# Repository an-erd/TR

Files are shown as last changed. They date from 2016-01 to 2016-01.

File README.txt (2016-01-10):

PURPOSE
=======
The function of TR is to have a tiny gym timer, which can give you intervals for active and rest
phases during gym or any other sport. Is has 4 buttons (1 reset button, and three functional
buttons T1..3 ), 9 leds (5 red as a progress bar, 3 orange for current phase active or rest, 
resp. (or during config), and a green heartbeat led.)
It is build on an ATMEL ATMEGA328P, but should work on any other similar MCU, too.
The power is assumed to be 3V. The code is optimized for power saving, but since the leds draw a
pretty high load, it is - by system - still consuming around 10 mA on average during training.

The program flow exist of the following steps:
- initialization (I/O pins, timer, ...)
- configuration routine
- training routine

During the phases, to control is done with the buttons, and the leds change the mode accordingly.
The specific status and control is shown in the list below.

The program itself makes heavy use of two timer, and pin change interrupts. The logic itself, in 
particular waiting for a counter to run down and to give effects and progress with the leds is
more or less completly delivered by the relevant interrupts. 

During WAITING MODE
====================
	LED PB1/green		-> slow flashing means "waiting for command"
	T1					-> (nothing yet)
	T2					-> go into config mode
	T3					-> GO! (training)

	LED PD0..7/red/ora	-> off
	LED PB1/green		-> short heartbeat

During CONFIG
=============
	T1					-> increase config parameter value, wrap-arolund 5 -> 1 or 0 resp.
	T2					-> switch to next config parameter, wrap-around is done
	T3					-> GO! (training)

	LED PD0..4/red		-> show configurated value
	LED PD5..7/orange	-> show configuration step (000/INT, 100/ACT, 110/REST, 111/cycles)
	LED PB1/green		-> fast flashing

During TRAINING
===============
	T1					-> (nothing yet)
	T2					-> Stop training and go in "waiting mode", see main loop
	T3					-> Pause training

	LED PD0..4/red		-> show progress in current phase, current step flashes, 1-5 leds
	LED PD5..7/orange	-> show LR or RL cascade to show phase ACTIVE or REST, resp.
	LED PB1/green		-> heartbeat

During PAUSE
============
	LED PD0..4/red		-> freeze current status 
	LED PD5..7/orange	-> freeze current status
	LED PB1/green		-> slow flashing

	T2					-> Stop training/pause and go in "waiting mode", see main loop
	T3					-> end pause, 

TODO and optimization
=====================
- none yet

Timer calculation/values
========================
- 8 MHz quartz, fuse CKDIV8 disabled, F_CPU=8000000UL
- timer0: 8 MHz,  8bit, 1/64  prescale -> 1 KHz (OCR0A   125 ticks / .001s=1ms)
- timer1: 8 MHz, 16bit, 1/256 prescale -> 1 Hz  (OCR1A 31250 Ticks / 1s, OCR1B 3125 Ticks / .1s)

- 8 MHz quartz, fuse CKDIV8 set, F_CPU=1000000UL
- timer0: @F_CPU/8, tick values stay unchanged
- timer1: @F_CPU/64, 1 Hz: OCR1A = 15625, 10 Hz: OCR1B =  1562

FUSE Settings are:
==================
BODLEVEL = 1V8
RSTDISBL = [ ]
DWEN = [ ]
SPIEN = [X]
WDTON = [ ]
EESAVE = [X]
BOOTSZ = 2048W_3800
BOOTRST = [ ]
CKDIV8 = [X]
CKOUT = [ ]
SUT_CKSEL = EXTXOSC_8MHZ_XX_16KCK_14CK_65MS

EXTENDED = 0xFE (valid)
HIGH = 0xD1 (valid)
LOW = 0x7F (valid)

Compiler symbols defined
========================
F_CPU=1000000UL
_PRODUCTION_TEST_ROUTINE_
_ALL_LED_ON_FOR_5_SEC_
_INCREASE_NUM_LED_ON_

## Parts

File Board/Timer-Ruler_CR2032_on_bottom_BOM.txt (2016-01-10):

Partlist

Exported from Timer-Ruler_CR2032_on_bottom.brd at 10.01.2016 20:31

EAGLE Version 7.5.0 Copyright (c) 1988-2015 CadSoft

Assembly variant: 

Part     Value                      Package          Library                                         Position (inch)       Orientation

B0       nur PAD, keine Stiftleiste 1X01             pinhead                                         (1.975 1.45)          R0
B2       nur PAD, keine Stiftleiste 1X01             pinhead                                         (1.975 1.55)          R0
JP1      nur PAD, keine Stiftleiste 2X03             pinhead                                         (1.6 1.625)           R180
LED1     Kingbright KP-2012SRC-PRV  CHIP-LED0805     led                                             (1.3 0.7)             R180
LED2     Kingbright KP-2012SRC-PRV  CHIP-LED0805     led                                             (1.4 0.7)             R180
LED3     Kingbright KP-2012SRC-PRV  CHIP-LED0805     led                                             (1.5 0.7)             R180
LED4     Kingbright KP-2012SRC-PRV  CHIP-LED0805     led                                             (1.6 0.7)             R180
LED5     Kingbright KP-2012SRC-PRV  CHIP-LED0805     led                                             (1.7 0.7)             R180
LED6     Kingbright KP-2012SECK     CHIP-LED0805     led                                             (1.8 0.7)             R180
LED7     Kingbright KP-2012SECK     CHIP-LED0805     led                                             (1.9 0.7)             R180
LED8     Kingbright KP-2012SECK     CHIP-LED0805     led                                             (2 0.7)               R180
LED9     Kingbright KP-2012CGCK     CHIP-LED0805     led                                             (2 0.875)             R0
R1       68R                        R0402            resistor                                        (1.275 0.925)         R270
R2       68R                        R0402            resistor                                        (1.325 0.925)         R270
R3       68R                        R0402            resistor                                        (1.375 0.925)         R270
R4       68R                        R0402            resistor                                        (1.425 0.925)         R270
R5       68R                        R0402            resistor                                        (1.475 0.925)         R270
R6       47R                        R0402            resistor                                        (1.725 0.9)           R270
R7       47R                        R0402            resistor                                        (1.775 0.9)           R270
R8       47R                        R0402            resistor                                        (1.825 0.9)           R270
R9       47R                        R0402            resistor                                        (1.875 0.9)           R270
R10      220R                       R0402            resistor                                        (1.26515748 1.6487313) R270
S1       431151015826               431181015816     Wurth_Elektronik_Electromechanic_Switchs_rev15b (1 1.175)             R180
S2       431151015826               431181015816     Wurth_Elektronik_Electromechanic_Switchs_rev15b (1 0.9)               R180
S3       431151015826               431181015816     Wurth_Elektronik_Electromechanic_Switchs_rev15b (1 0.625)             R180
SCL      nur PAD, keine Stiftleiste 1X01             pinhead                                         (0.9 1.4)             R90
SDA      nur PAD, keine Stiftleiste 1X01             pinhead                                         (1 1.4)               R0
U$1      FIDUCIAL                   FIDUCIAL_1MM     adafruit                                        (0.95 0.625)          R0
U$2      FIDUCIAL                   FIDUCIAL_1MM     adafruit                                        (1.975 1.675)         R90
U$3      RENATA_STMU2032            SMTU2032         Ava                                             (1.525 1.125)         MR55
U$4      C+K_AYZ0202AGRLC           C+K_AYZ0202AGRLC Ava                                             (1 1.6)               R180
U1       ATMEGA328P_TQFP            TQFP32-08        SparkFun-DigitalIC                              (1.45 1.25)           R135
Y1       8MHZ                       RESONATOR-SMD    SparkFun-FreqCtrl                               (1.625 0.975)         R45

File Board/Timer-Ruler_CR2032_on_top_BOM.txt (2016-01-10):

Partlist

Exported from Timer-Ruler_CR2032_on_top.brd at 10.01.2016 20:29

EAGLE Version 7.5.0 Copyright (c) 1988-2015 CadSoft

Assembly variant: 

Part     Value                      Package          Library                                         Position (inch)       Orientation

B0       nur PAD, keine Stiftleiste 1X01             pinhead                                         (2.275 1.675)         R0
B2       nur PAD, keine Stiftleiste 1X01             pinhead                                         (2.175 1.675)         R0
JP1      ISP                        2X03             pinhead                                         (1.45 1.625)          R180
LED1     Kingbright KP-2012SRC-PRV  CHIP-LED0805     led                                             (1.3 0.6)             R180
LED2     Kingbright KP-2012SRC-PRV  CHIP-LED0805     led                                             (1.4 0.6)             R180
LED3     Kingbright KP-2012SRC-PRV  CHIP-LED0805     led                                             (1.5 0.6)             R180
LED4     Kingbright KP-2012SRC-PRV  CHIP-LED0805     led                                             (1.6 0.6)             R180
LED5     Kingbright KP-2012SRC-PRV  CHIP-LED0805     led                                             (1.7 0.6)             R180
LED6     Kingbright KP-2012SECK     CHIP-LED0805     led                                             (1.85 0.6)            R180
LED7     Kingbright KP-2012SECK     CHIP-LED0805     led                                             (1.95 0.6)            R180
LED8     Kingbright KP-2012SECK     CHIP-LED0805     led                                             (2.05 0.6)            R180
LED9     Kingbright KP-2012CGCK     CHIP-LED0805     led                                             (2.525 0.5)           R180
R1       68R                        R0402            resistor                                        (1.275 0.825)         R270
R2       68R                        R0402            resistor                                        (1.325 0.825)         R270
R3       68R                        R0402            resistor                                        (1.375 0.825)         R270
R4       68R                        R0402            resistor                                        (1.425 0.825)         R270
R5       68R                        R0402            resistor                                        (1.475 0.825)         R270
R6       47R                        R0402            resistor                                        (1.7 0.825)           R270
R7       47R                        R0402            resistor                                        (1.75 0.825)          R270
R8       47R                        R0402            resistor                                        (1.8 0.825)           R270
R9       47R                        R0402            resistor                                        (2.425 0.55)          R0
R10      220R                       R0402            resistor                                        (1.26515748 1.6487313) R270
S1       431151015826               431181015816     Wurth_Elektronik_Electromechanic_Switchs_rev15b (1 1.1)               R180
S2       431151015826               431181015816     Wurth_Elektronik_Electromechanic_Switchs_rev15b (1 0.825)             R180
S3       431151015826               431181015816     Wurth_Elektronik_Electromechanic_Switchs_rev15b (1 0.55)              R180
SCL      nur PAD, keine Stiftleiste 1X01             pinhead                                         (0.9 1.3)             R90
SDA      nur PAD, keine Stiftleiste 1X01             pinhead                                         (0.9 1.4)             R0
U$1      FIDUCIAL                   FIDUCIAL_1MM     adafruit                                        (0.95 0.55)           R0
U$2      FIDUCIAL                   FIDUCIAL_1MM     adafruit                                        (2.525 1.7)           R90
U$3      RENATA_STMU2032            SMTU2032         Ava                                             (2.15 1.175)          R125.6
U$4      C+K_AYZ0202AGRLC           C+K_AYZ0202AGRLC Ava                                             (1 1.6)               R180
U1       ATMEGA328P_TQFP            TQFP32-08        SparkFun-DigitalIC                              (1.45 1.25)           R135
Y1       8MHZ                       RESONATOR-SMD    SparkFun-FreqCtrl                               (1.65 1)              R45

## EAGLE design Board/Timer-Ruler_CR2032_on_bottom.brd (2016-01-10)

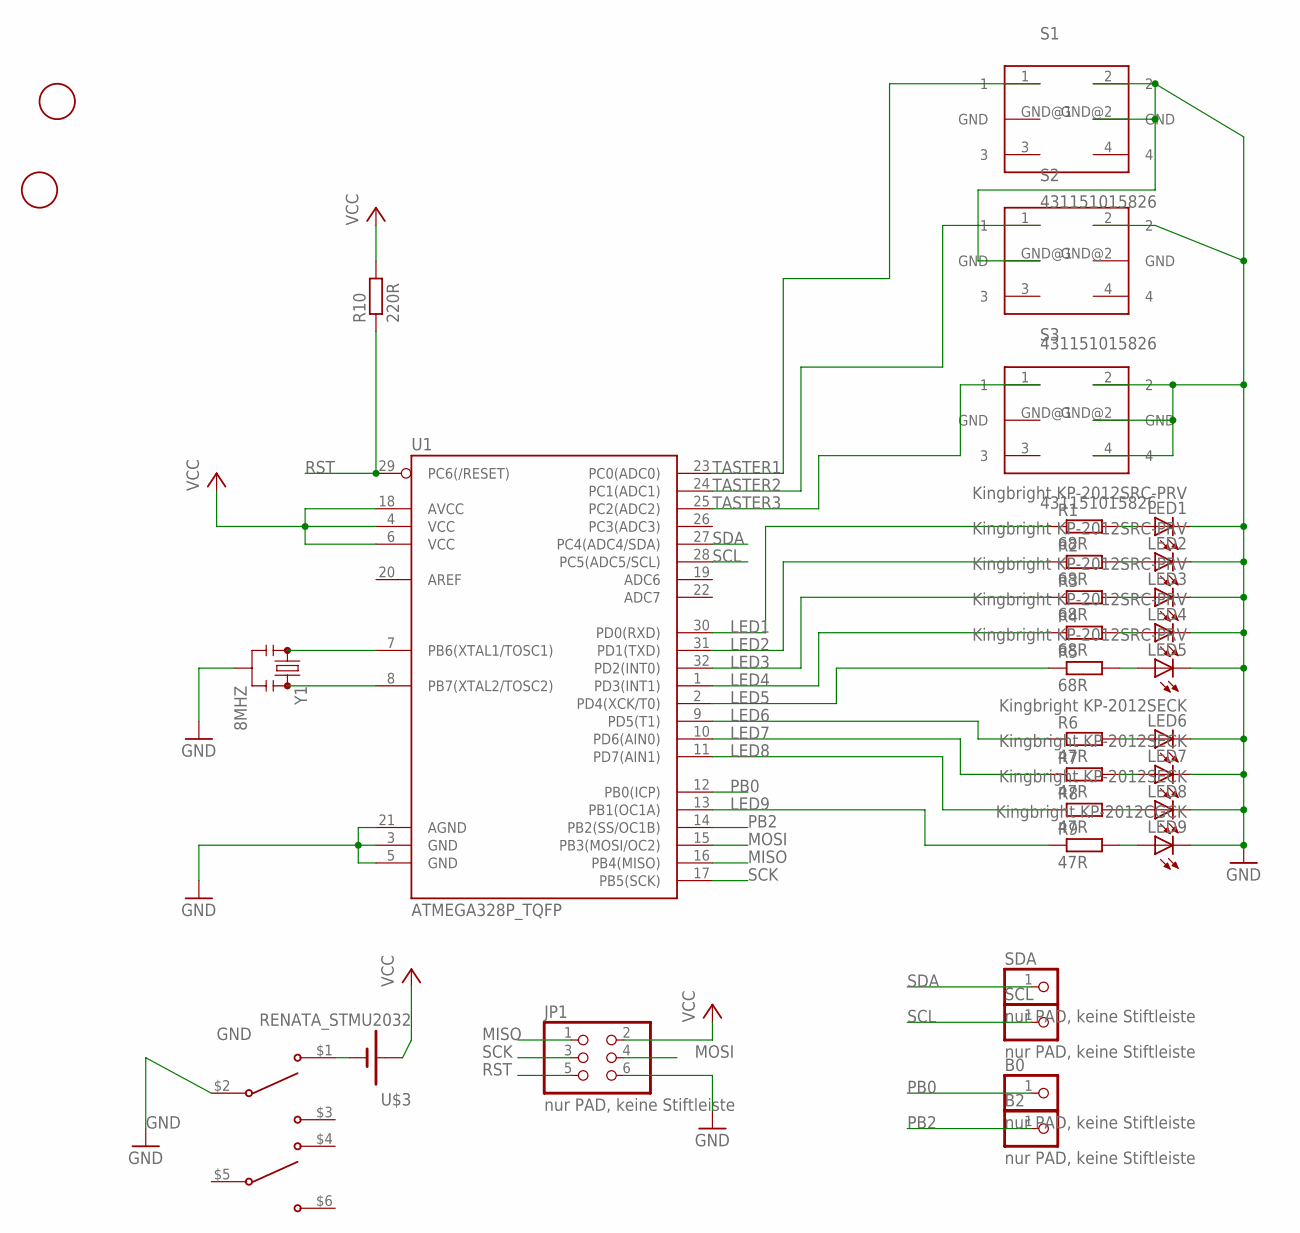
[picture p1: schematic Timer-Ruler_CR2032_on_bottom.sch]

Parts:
B0, B2: nur PAD, keine Stiftleiste; 1X01
JP1: nur PAD, keine Stiftleiste; 2X03
LED1, LED2, LED3, LED4, LED5: Kingbright KP-2012SRC-PRV; CHIP-LED0805
LED6, LED7, LED8: Kingbright KP-2012SECK; CHIP-LED0805
LED9: Kingbright KP-2012CGCK; CHIP-LED0805
R1, R2, R3, R4, R5: 68R; R0402
R6, R7, R8, R9: 47R; R0402
R10: 220R; R0402
S1, S2, S3: 431151015826; 431181015816
SCL: nur PAD, keine Stiftleiste; 1X01
SDA: nur PAD, keine Stiftleiste; 1X01
U1: ATMEGA328P_TQFP; TQFP32-08
U$1, U$2: FIDUCIAL; FIDUCIAL_1MM
U$3: RENATA_STMU2032; SMTU2032
U$4: C+K_AYZ0202AGRLC
Y1: 8MHZ; RESONATOR-SMD

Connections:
GND: JP1.6, LED1.C, LED2.C, LED3.C, LED4.C, LED5.C, LED6.C, LED7.C, LED8.C, LED9.C, S1.2, S1.GND@2 (GND), S2.2, S2.GND@1 (GND), S3.2, S3.4, S3.GND@2 (GND), U1.3 (GND), U1.5 (GND), U1.21 (AGND), U$4.$2 (2), Y1.2
LED1: R1.1, U1.30 (PD0(RXD))
LED2: R2.1, U1.31 (PD1(TXD))
LED3: R3.1, U1.32 (PD2(INT0))
LED4: R4.1, U1.1 (PD3(INT1))
LED5: R5.1, U1.2 (PD4(XCK/T0))
LED6: R6.1, U1.9 (PD5(T1))
LED7: R7.1, U1.10 (PD6(AIN0))
LED8: R8.1, U1.11 (PD7(AIN1))
LED9: R9.1, U1.13 (PB1(OC1A))
MISO: JP1.1, U1.16 (PB4(MISO))
MOSI: JP1.4, U1.15 (PB3(MOSI/OC2))
unnamed: LED1.A, R1.2
unnamed: LED2.A, R2.2
unnamed: LED3.A, R3.2
unnamed: LED4.A, R4.2
unnamed: LED5.A, R5.2
unnamed: LED6.A, R6.2
unnamed: LED7.A, R7.2
unnamed: LED8.A, R8.2
unnamed: LED9.A, R9.2
unnamed: U1.7 (PB6(XTAL1/TOSC1)), Y1.1
unnamed: U1.8 (PB7(XTAL2/TOSC2)), Y1.3
unnamed: U$3.-, U$4.$1 (1)
PB0: B0.1, U1.12 (PB0(ICP))
PB2: B2.1, U1.14 (PB2(SS/OC1B))
RST: JP1.5, R10.1, U1.29 (PC6(/RESET))
SCK: JP1.3, U1.17 (PB5(SCK))
SCL: SCL.1, U1.28 (PC5(ADC5/SCL))
SDA: SDA.1, U1.27 (PC4(ADC4/SDA))
TASTER1: S1.1, U1.23 (PC0(ADC0))
TASTER2: S2.1, U1.24 (PC1(ADC1))
TASTER3: S3.1, U1.25 (PC2(ADC2))
VCC: JP1.2, R10.2, U1.4 (VCC), U1.6 (VCC), U1.18 (AVCC), U$3.+

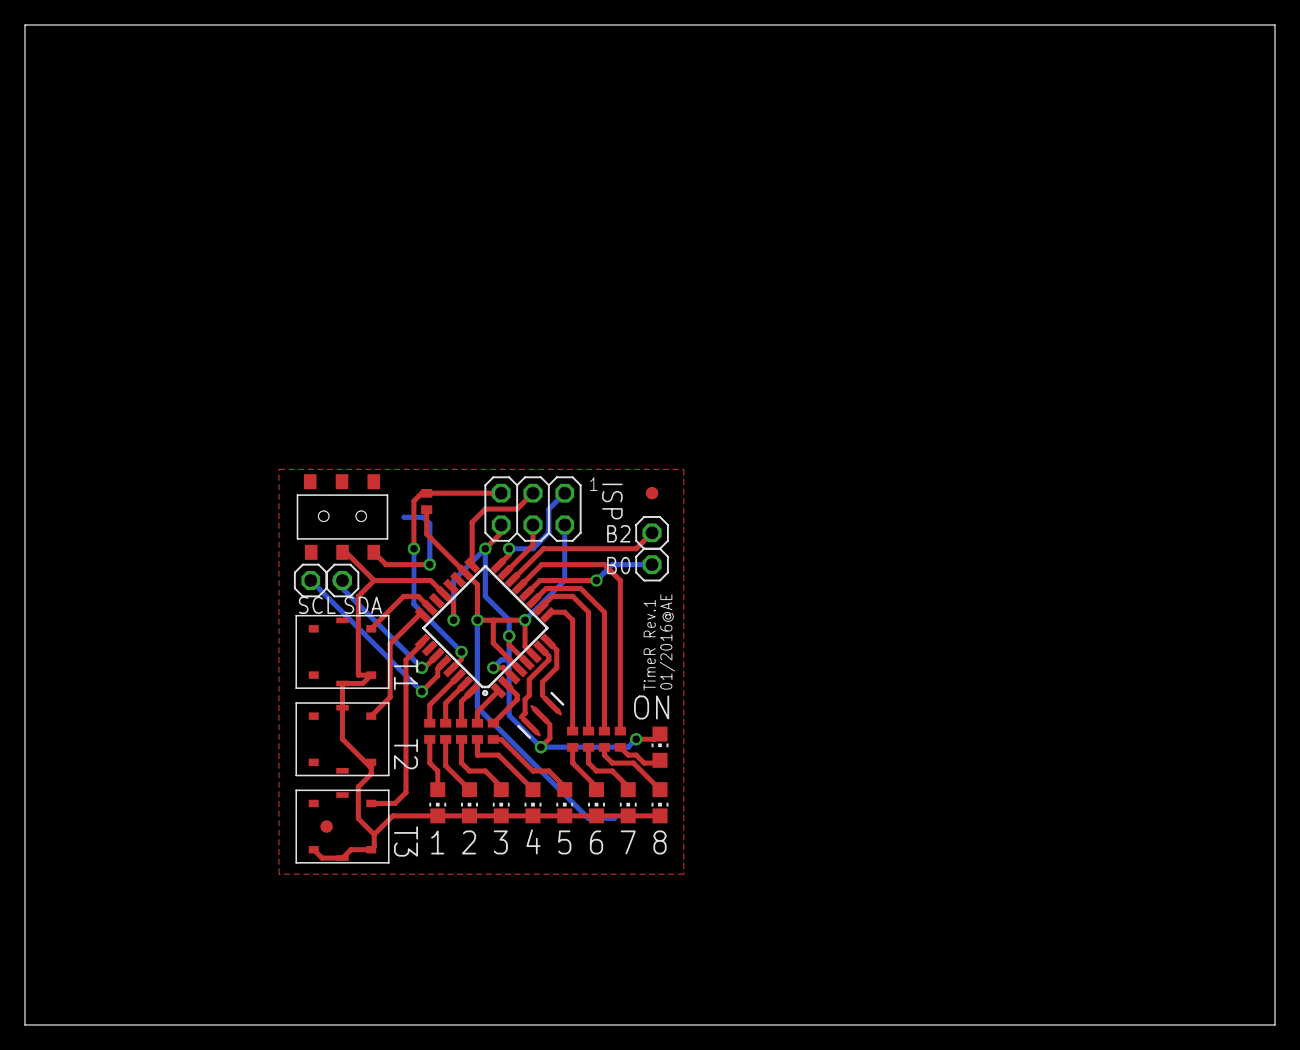
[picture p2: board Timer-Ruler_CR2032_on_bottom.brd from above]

Board: 2 copper layers, 100.0 x 80.0 mm, 33 parts (1 on the bottom side), 34 nets.

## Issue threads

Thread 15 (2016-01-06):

undefined orange led flickering

an-erd, 2016-01-06:
sometimes, in particular when w/o ATMEL-ICE some strange orange led things occur.
Seems to be an issue w/updating the led effect downward counter and orange_led_current_step. Rewrite necessary

Closed 2016-01-06.

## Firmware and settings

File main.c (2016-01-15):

/*
 * TimerRuler.c
 *
 * Created: 22.11.2015 10:51:17
 * Author : AKAEM
 */ 

/* atmega328p ports used:
	 PC0	Switch T1	PCINT8		0
	 PC1	Switch T2	PCINT9		1
	 PC2	Switch T3	PCINT10		2
	(PC4	I2C SDA		unused)
	(PC5	I2C SCL		unused)
	 PD0	LED1 RED				0
	 PD1	LED2 RED				1
	 PD2	LED3 RED				2
	 PD3	LED4 RED				3
	 PD4	LED5 RED				4
	 PD5	LED6 ORANGE				5
	 PD6	LED7 ORANGE				6
	 PD7	LED8 ORANGE				7
	 PB1 	LED9 GREEN				8
*/

#include <avr/io.h>
#include <avr/interrupt.h>
#include <avr/eeprom.h>
#include <avr/sleep.h>
#include <avr/power.h>
#include <avr/wdt.h>
#include <util/delay.h>

#include "bitoperations.h"
#include "timerruler_struct.h"
#include "timerruler_const.h"
#include "timerruler_led.h"

uint8_t						config_params_ee[NUM_CONFIG_PARAMS] EEMEM	= {1, 4, 4, 3};
volatile static	uint8_t		PINChistory = 0x00;

void main(void) __attribute__((noreturn));

// global variables
volatile sGlobalStatus program_status = {
	.phase							= PHASE_RESET,
	.current_led_step				= 0,
	.buttons						= {{DEBOUNCE_THRESHOLD,0,0,0,},{DEBOUNCE_THRESHOLD,0,0,0,},{DEBOUNCE_THRESHOLD,0,0,0,},},
	.green_led_mode					= LED_OFF,
	.green_led_max_cycle			= 0,
	.green_led_current_cycle		= 0,
	.green_led_OCR1B_basis			= 0,
	.led_effect_ongoing				= LED_OFF,
	.effect_led_ms_counter			= LED_EFFECT_DELAY,
	.effect_led_current_step		= 0,
	.effect_led_direction			= ALL_LED_CENTER_EFFECT_LR,
	.orange_led_period				= 0,
	.backward_cnt_sec_to_deep_sleep = DEEP_SLEEP_SEC_MAINPROG,
};

ISR ( TIMER0_COMPA_vect )
{
	volatile uint8_t	button_backward_cnt = NUM_SWITCHES;
	volatile uint8_t	PORTD_modified;
		
	// fired every 1ms gone

	// button debounce mechanism for T1..3 (PC0..2)
	// - the button is assumed to be stable if "pressed" status occurs 50x (=50ms) in a row
	// - temp_state_button_pressed is set in pin change interrupt routine (ISR (PCINT1_vect))
	//
	// - program flow
	//		a) if not temp_pressed (filled from ISR) 
	//		a1)	-> do: reset counter, and clear the "wait for release" bit
	//		a2) -> else: (if not "waiting for release", inc in-a-row-counter and
	//			if threshold reached -> set the "button pressed" flag
	while (button_backward_cnt--) {
		if ( !program_status.buttons[button_backward_cnt].temp_state_button_pressed ) {
			program_status.buttons[button_backward_cnt].backward_cnt_high_in_a_row = DEBOUNCE_THRESHOLD;
			program_status.buttons[button_backward_cnt].temp_wait_for_button_release = 0;		
		} else {
			if (! program_status.buttons[button_backward_cnt].temp_wait_for_button_release) {
				if (! --program_status.buttons[button_backward_cnt].backward_cnt_high_in_a_row ){
					program_status.buttons[button_backward_cnt].button_pressed = 1;					// debounce interval gone -> stable
					program_status.buttons[button_backward_cnt].temp_wait_for_button_release = 1;
				}
			}
		}
	}

	// the led effects are done w/TIMER0/A, delay between effects w/TIMER1/A
	if (program_status.effect_led_current_step){
		switch (program_status.led_effect_ongoing){
			case LED_EFFECT_ORANGE:
				if(program_status.phase & BIT(PHASE_TRAINING)){
			 		if (! --program_status.effect_led_ms_counter){
 						program_status.effect_led_ms_counter = LED_EFFECT_DELAY;
		 				program_status.effect_led_current_step--;
 
	 					PORTD_modified = PORTD;
 						bit_clear(PORTD_modified, LED_PORTD_ORANGE);
	 					bit_set(PORTD_modified, ledArrayOrangeEffect[program_status.effect_led_current_step][(bit_get(program_status.phase, BIT(PHASE_ACTIVE))) ? 0 : 1] );	
 						PORTD = PORTD_modified;
 					}
 				}
				break;
			case LED_EFFECT_ALL:
				if (! --program_status.effect_led_ms_counter){
					program_status.effect_led_ms_counter = LED_EFFECT_DELAY;
					program_status.effect_led_current_step--;
					PORTD = ledArrayAllEffect[program_status.effect_led_current_step][program_status.effect_led_direction];
				}
 				break;	
			case LED_EFFECT_CENTER:
				if (! --program_status.effect_led_ms_counter){
					program_status.effect_led_ms_counter = LED_EFFECT_DELAY;
					program_status.effect_led_current_step--;
					PORTD = ledArrayAllCenterEffect[program_status.effect_led_current_step];
				}
 				break;
			case LED_OFF:
				break;
			default:
				break;
		}
	}
}

ISR ( TIMER1_COMPA_vect )
{
	// 1s gone
	
	// green led tasks
	switch (program_status.green_led_mode) {
		case HEARTBEAT_LED:
			led_set(LED9, OFF);		// no change in compare value, hit comp B in next cycle
			break;
		case SHORT_HEARTBEAT_LED:
			led_set(LED9, OFF);		// no change in compare value, hit comp B in next cycle
			break;
		case FAST_FLASHING_LED:
			led_flip(LED9);			// OCR1B and .green_led_current_cycle already set in comp B
			break;
		case SLOW_FLASHING_LED:
			led_set(LED9, OFF);		// no change in compare value, hit comp B in next cycle
			break;
		case LED_OFF:				// nothing to do, should be off
			break;
		default:
			break;
	}
	
	if ( bit_get(program_status.phase, BIT(PHASE_TRAINING))){
		if (! --program_status.backward_counter_sec_to_go){
			bit_set(PORTD, BIT(program_status.current_led_step));
		} else {
			bit_flip(PORTD, BIT(program_status.current_led_step));
		}
		
		if (! --program_status.orange_led_period) {
			program_status.orange_led_period		= ORANGE_LED_EFFECT_PERIOD;
			program_status.effect_led_current_step	= ORANGE_LED_EFFECT_STEPS;	// fire effect w/orange leds
		}
	}
			
	if ( bit_get(program_status.phase, BIT(PHASE_MAINPROG)|BIT(PHASE_CONFIG)|BIT(PHASE_PAUSE))){
		--program_status.backward_cnt_sec_to_deep_sleep;
	}
}

ISR ( TIMER1_COMPB_vect )
{
	// update only green led 
	switch (program_status.green_led_mode) {
		case HEARTBEAT_LED:
			led_set(LED9, ON);		// no change in compare value, hit comp A in next cycle
			break;
		case SHORT_HEARTBEAT_LED:
			led_set(LED9, ON);		// no change in compare value, hit comp A in next cycle
			break;
		case FAST_FLASHING_LED:
			led_flip(LED9);
			if (--program_status.green_led_current_cycle){
				OCR1B += program_status.green_led_OCR1B_basis;	// prepare for next hit/cycle
			} else {
				OCR1B  = program_status.green_led_OCR1B_basis;	// reinitialize compare value for next cycle to first hit
				program_status.green_led_current_cycle = program_status.green_led_max_cycle; // reinitialize cycle counter
			}
			break;
		case SLOW_FLASHING_LED:
			led_set(LED9, ON);		// hit comp A in next cycle
			break;
		case LED_OFF: 				// should already be off
			break; 
		default:
			break;
	}
}

ISR ( PCINT1_vect )
{
	volatile uint8_t changedbits;

	// Interrupt routine handles pin chance interrupts for PC0..2
	// if a button changes the state, .temp_state_button_pressed is updated
	// results are evaluated (in particular, debouncing) in ISR (TIMER0_COMPA_vect), 
	// and used throughout the program by program_status.Tx.button_pressed, which then need to be cleared again
	
	changedbits = PINC ^ PINChistory;
	PINChistory = PINC;

	if(bit_get(changedbits, BIT(PINC0))){
		program_status.buttons[0].temp_state_button_pressed = !bit_get(PINC, BIT(PINC0));
	}
	if(bit_get(changedbits, BIT(PINC1))){
		program_status.buttons[1].temp_state_button_pressed = !bit_get(PINC, BIT(PINC1));
	}
	if(bit_get(changedbits, BIT(PINC2))){
		program_status.buttons[2].temp_state_button_pressed = !bit_get(PINC, BIT(PINC2));
	}
}

void init_global_vars(void)
{
	program_status.phase = PHASE_RESET;
}

void init_io_pins(void)
{
	// power consumption 480 uA in IDLE mode -> 20.8 uA PWR_DOWN
	DDRB  = BIT(DDB1);				// PB1 as output, all other as input
	PORTB = 0xFD;					// all input w/pull-ups
	DDRC  = 0x00;					// all port C as input
	PORTC = 0x7F;					// PC0..2 used for switches, but set all w/pull-ups
	DDRD  = 0xFF;					// all port D as output (all PD0..7 used for LEDs)
	
	bit_set(PCICR,  BIT(PCIE1));							// pin change interrupt enable
	bit_set(PCMSK1, BIT(PCINT8)|BIT(PCINT9)|BIT(PCINT10) );	// Enable pin change detection

	PINChistory = PINC;
}

void init_timers(void)
{
	// prepare timer0 and timer1
	// - timer0a: switch debounce (1 KHz interrupts), and 3 orange led effect
	// - timer1a: training phase measurement (1 HZz) and 5 red led progress bar 
	// - timer1b: used together with timer1a to get a GREEN LED heartbeat (.1ms/.9s blink), of green flashing led

	// timer0
	bit_set(TCCR0A, BIT(WGM01));				// Configure timer0 for CTC mode,
	bit_set(TCCR0B, BIT(CS01));					// Start timer @F_CPU/8
	OCR0A	= 124;								// 8 MHz, 8bit, CKDIV8 set, 1/8 prescale -> 1 KHz (125 ticks / .001s=1ms
	bit_set(TIMSK0, BIT(OCIE0A));				// Enable Timer/Counter Compare Match A interrupt
	
	// timer1
	bit_set(TCCR1B, BIT(WGM12)|BIT(CS11)|BIT(CS10)); // Configure timer1 for CTC mode, start timer @F_CPU/64
	OCR1A	= 15625; 							// 8 MHz, 16bit, CKDIV8 set, 1/64 prescale -> 1 Hz (= 15625 Ticks/ 1s)
	OCR1B	=  1562;							// and 1562 Ticks / .1s
	bit_set(TIMSK1, BIT(OCIE1A)|BIT(OCIE1B)); 	// Enable Timer/Counter Compare Match interrupt on both channel A and B
}

void restart_timer1(void)
{
	uint8_t history_TCCR1B = TCCR1B & (BIT(CS10)|BIT(CS11)|BIT(CS12));

	bit_clear(TCCR1B, history_TCCR1B);	// stop clock
	TCNT1 = 0;							// reset TCNT1 counter
	led_set(LED9, OFF);
	OCR1B = program_status.green_led_OCR1B_basis;	// set correct OCR1B compare value
	bit_set(TCCR1B, history_TCCR1B);			// start clock
}

void set_green_led_mode(uint8_t led_mode)
{
	// set configuration parameters for green led,
	// actual handling is done in ISR for timer1 compare match A/B
	switch (led_mode) {
		case LED_OFF:
			program_status.green_led_mode			= LED_OFF;
			program_status.green_led_max_cycle		= 0;
			program_status.green_led_current_cycle	= 0;
			program_status.green_led_OCR1B_basis	= 0;
			break;
		case FAST_FLASHING_LED:
			// 4 Hz
			program_status.green_led_mode			= FAST_FLASHING_LED;
			program_status.green_led_max_cycle		= 7;
			program_status.green_led_current_cycle	= program_status.green_led_max_cycle;
			program_status.green_led_OCR1B_basis	= 1953;
			break;
		case SLOW_FLASHING_LED:
			// 1 Hz
			program_status.green_led_mode = SLOW_FLASHING_LED;
			// .green_led_max_cycle and .green_led_current_cycle not necessary (only one cycle)
			program_status.green_led_OCR1B_basis = 7812;
			break;
		case HEARTBEAT_LED:
			// 1 cycle: 0 -> .9s OFF.1s ON
			program_status.green_led_mode = HEARTBEAT_LED;
			// .green_led_max_cycle and .green_led_current_cycle not necessary (only one cycle)
			program_status.green_led_OCR1B_basis = 14062;
			break;
		case SHORT_HEARTBEAT_LED:
			// just blink very short...
			program_status.green_led_mode = SHORT_HEARTBEAT_LED;
			// .green_led_max_cycle and .green_led_current_cycle not necessary (only one cycle)
			program_status.green_led_OCR1B_basis = 15400;
			break;
		default:
			break;
	}
	restart_timer1();
}

void set_led_effect(const uint8_t led_effect)
{
	switch(led_effect){
		case LED_EFFECT_ORANGE:
			program_status.orange_led_period		= 0;
			program_status.effect_led_current_step	= 0;
			program_status.led_effect_ongoing		= LED_EFFECT_ORANGE;
			break;
		case LED_EFFECT_ALL:
			program_status.orange_led_period		= 0;
			program_status.effect_led_current_step	= 0;
			program_status.led_effect_ongoing		= LED_EFFECT_ALL;
			break;
		case LED_EFFECT_CENTER:
			program_status.orange_led_period		= 0;
			program_status.effect_led_current_step	= 0;
			program_status.led_effect_ongoing		= LED_EFFECT_CENTER;
			break;
		case LED_OFF:
			program_status.orange_led_period		= 0;
			program_status.effect_led_current_step	= 0;
			program_status.led_effect_ongoing		= LED_OFF;
			break;
		default:
			break;
	}
}

void set_led_effect_all_direction(const uint8_t led_effect_direction)
{
	program_status.effect_led_direction = led_effect_direction;
}

void start_led_effect(void)
{
	switch(program_status.led_effect_ongoing){
		case LED_EFFECT_ORANGE:
			program_status.orange_led_period		= ORANGE_LED_EFFECT_PERIOD;
			break;
		case LED_EFFECT_ALL:
			program_status.effect_led_current_step	= ALL_LED_EFFECT_STEPS;
			break;
		case LED_EFFECT_CENTER:
			program_status.effect_led_current_step	= ALL_LED_CENTER_EFFECT_STEPS;
			break;
		default:
			break;
	}
}

void all_led_effect_and_wait_to_complete(const uint8_t led_effect_direction)
{
	uint8_t tmp_phase = program_status.phase;
	
	bit_clear(program_status.phase, BIT(PHASE_TRAINING));
	set_led_effect(LED_EFFECT_ALL);
	set_led_effect_all_direction(led_effect_direction);
	start_led_effect();
	do {} while (program_status.effect_led_current_step);
	set_led_effect(LED_OFF);
	program_status.phase = tmp_phase;
}

void center_led_effect_and_wait_to_complete(void)
{
	uint8_t tmp_phase = program_status.phase;
	
	bit_clear(program_status.phase, BIT(PHASE_TRAINING));
	set_led_effect(LED_EFFECT_CENTER);
	start_led_effect();
	do {} while (program_status.effect_led_current_step);
	set_led_effect(LED_OFF);
	program_status.phase = tmp_phase;
}

void enable_ppr(void)
{
	power_adc_disable();				// Analog to Digital Converter module
	power_spi_disable();				// Serial Peripheral Interface module
	power_timer0_enable();				// timer0 module
	power_timer1_enable();				// timer1 module
	power_timer2_disable();				// timer2 module
	power_twi_disable();				// Two Wire Interface module
	power_usart0_disable();				// USART module
	// Turn off brownout detection
}

void touch_deep_sleep_counter(void)
{
	if(bit_get(program_status.phase, BIT(PHASE_MAINPROG))){
		program_status.backward_cnt_sec_to_deep_sleep = DEEP_SLEEP_SEC_MAINPROG;
	} else if(bit_get(program_status.phase, BIT(PHASE_CONFIG))){
		program_status.backward_cnt_sec_to_deep_sleep = DEEP_SLEEP_SEC_CONFIG;
	} else if(bit_get(program_status.phase, BIT(PHASE_PAUSE))){
		program_status.backward_cnt_sec_to_deep_sleep = DEEP_SLEEP_SEC_TRAINING_PAUSE;
	}
}

void go_to_appropriate_sleep_mode(void)
{
	sleep_bod_disable();
	sleep_mode();
	if (! program_status.backward_cnt_sec_to_deep_sleep){
		volatile uint8_t preserve_PIND = PIND;
		bit_clear(PORTD, LED_PORTD);
		set_sleep_mode(SLEEP_MODE_PWR_DOWN);
		sleep_bod_disable();
		sleep_mode();
		set_sleep_mode(SLEEP_MODE_IDLE);
		PIND = preserve_PIND;
		touch_deep_sleep_counter();
	}
}

void read_permanent_config_params()
{
	eeprom_read_block((void*) program_status.config_params, (const void*) config_params_ee, NUM_CONFIG_PARAMS);
}

void perform_phase_config(void)
{
	uint8_t immediate_go		= 0;
	uint8_t loop_counter		= 0;
	uint8_t tmp_config_value	= 0;

	const uint8_t	config_params_min_max[NUM_CONFIG_PARAMS][2] = {{1,5},{1,5},{1,5},{0,5}};
	
	program_status.phase = BIT(PHASE_CONFIG);		// set phase to CONFIG, no "|" necessary, just set
	set_green_led_mode(FAST_FLASHING_LED);			// green led flashing fast -> configuration mode
		
	// The configuration routine is essentially a loop using the same code to complete or update config params,
	// using an index, i.e. 
	//
	// while (! Button T3 pressed)
	// for i in
	//		0 -> CONFIG_INTERVAL_CNT
	//		1 -> CONFIG_NR_INTERVAL_ACTIVE
	//		2 -> CONFIG_NR_INTERVAL_REST
	//		3 -> CONFIG_NR_CYCLES
	// do
	//		update orange leds PD5..7 with 0 to all three leds according to i
	//		press T1 X-times -> red leds PD0..4 show the count according to the click counter
	//		press T2 for next step in "for i" loop and wraparound 0->1->2->3->0
	//			or press T3 to leave configuration mode and GO!
	//	done
	// 
	// Details:
	//		Step 1)		press T1 x times -> x * 15 sec Intervall, store counter in .config_params[1..3]
	//					(red leds show counter 1-5, orange leds off; 5 red -> 5 * 75 sec max)
	//		Step 2-4)	press T1 x time -> store counter in .config_params[1..3]
	//					(red leds show counter 1-5, orange leds 1, 2 or all 3 are on)
	do {
		tmp_config_value = program_status.config_params[loop_counter];
		PORTD = ledArrayRedCascade_LR[tmp_config_value] | ledArrayOrangeCascade_LR[loop_counter];
		touch_deep_sleep_counter();		
		
		// wait for key pressed
		while (! program_status.buttons[0].button_pressed && ! program_status.buttons[1].button_pressed
			&& !  program_status.buttons[2].button_pressed ){
			go_to_appropriate_sleep_mode();
		}
		
		if (program_status.buttons[0].button_pressed){
			program_status.buttons[0].button_pressed = 0;
			tmp_config_value++;
			if (tmp_config_value > config_params_min_max[loop_counter][1]){
				tmp_config_value = config_params_min_max[loop_counter][0];
			}
			PORTD = ledArrayRedCascade_LR[tmp_config_value] | ledArrayOrangeCascade_LR[loop_counter];
			program_status.config_params[loop_counter] = tmp_config_value;	// write config back
		} 
		if (program_status.buttons[1].button_pressed){
			// T2 hit -> next configuration parameter, and wraparound
			program_status.buttons[1].button_pressed = 0;
			loop_counter++;
			loop_counter %= NUM_CONFIG_PARAMS;
		}
		if (program_status.buttons[2].button_pressed){
			// T3 hit -> GO! with this configuration
			program_status.buttons[2].button_pressed = 0;
			immediate_go++;
		}
	} while (! immediate_go);

	set_green_led_mode(LED_OFF);
	led_set_all(OFF);
	
	program_status.phase = BIT(PHASE_MAINPROG);
}

void store_config_params_permanently()
{
	cli();
	eeprom_busy_wait();
	eeprom_update_block((const void*) program_status.config_params, (void*) config_params_ee, NUM_CONFIG_PARAMS);
	sei();
}

void perform_phase_config_calculation(void)
{
	uint8_t const temp_interval_basis_sec = INTERVAL_LENGTH * program_status.config_params[CONFIG_INTERVAL_CNT];
	uint8_t temp_multiplied_interval_length;
	
	// current steps blinks .5 Hz (on/off in 2 secs), completed steps on,
	// orange leds PB5..7 show phase (ACTIVE: L->R, REST: R->L)

	// calculation of red leds PB0..4 (L->R)
	// for ACTIVE phase:
	temp_multiplied_interval_length =
		temp_interval_basis_sec * program_status.config_params[CONFIG_NR_INTERVAL_ACTIVE];
	program_status.led_steps_threshold[0][0] = temp_multiplied_interval_length / 5;
	program_status.led_steps_threshold[1][0] =
		program_status.led_steps_threshold[0][0] + temp_multiplied_interval_length % 5;
	// for REST phase:
	temp_multiplied_interval_length =
		temp_interval_basis_sec * program_status.config_params[CONFIG_NR_INTERVAL_REST];
	program_status.led_steps_threshold[0][1] = temp_multiplied_interval_length / 5;
	program_status.led_steps_threshold[1][1] =
		program_status.led_steps_threshold[0][1] + temp_multiplied_interval_length % 5;
}
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
void main(void)
{
	uint8_t	go_to_training_next = 0;
	
	// overall program sketch
	//	1) initialization (global vars, I/O pins, timers, interrupts, ...)
	//	2) button T1 -> nothing yet
	//	   button T2 -> PHASE CONFIG: user input for interval multiplier, #active and #rest intervals, #cycles
	//	   button T3 -> PHASE TRAINING: perform ACTIVE and REST alternately, until #cycles reached or do it endlessly
	//
	//	also using switches during training: 
	//		- view number cycles achieved		TODO
	//		- view config						TODO
	
	// Initialization
	init_global_vars();
	init_io_pins();
	init_timers();
	wdt_disable();
	enable_ppr();						// set PRR (power reduction register)
	sei();

	program_status.phase = BIT(PHASE_MAINPROG);
	
#ifdef _PRODUCTION_TEST_ROUTINE_
	// flash of all leds to check after production
	led_set_all(ON); _delay_ms(10); led_set_all(OFF); _delay_ms(200);
#endif //_PRODUCTION_TEST_ROUTINE_

#ifdef _ALL_LED_ON_FOR_5_SEC_
	// to measure power consumption
	led_set_all(ON); _delay_ms(5000);led_set_all(OFF); _delay_ms(200);
#endif // _ALL_LED_ON_FOR_5_SEC_

#ifdef _INCREASE_NUM_LED_ON_
	// to measure power consumption
 	uint8_t temp_cnt;
 	led_set_all(OFF);
 	for (temp_cnt=0;temp_cnt<9;temp_cnt++)
 	{
 		_delay_ms(5000);
 		led_set(temp_cnt, ON);
 	}
#endif // _INCREASE_NUM_LED_ON_

	read_permanent_config_params();
	perform_phase_config_calculation();
	set_sleep_mode(SLEEP_MODE_IDLE);	// two different stages will be used, IDLE if heartbeat is on, and later PWR_DOWN
	set_green_led_mode(SHORT_HEARTBEAT_LED);
	
	while (1)	{
		touch_deep_sleep_counter();
		do {
			go_to_appropriate_sleep_mode();
		} while ( !program_status.buttons[0].button_pressed && !program_status.buttons[1].button_pressed 
			&& !program_status.buttons[2].button_pressed);
		
		// button T1 -> do nothing 
		if (program_status.buttons[0].button_pressed){
			program_status.buttons[0].button_pressed = 0;
		}
		
		// button T2 -> config
		if (program_status.buttons[1].button_pressed){
			program_status.buttons[1].button_pressed = 0;
			perform_phase_config();
			store_config_params_permanently();
			perform_phase_config_calculation();
			
			go_to_training_next = 1;			
		}

		// button T3 -> training
		if (program_status.buttons[2].button_pressed){
			program_status.buttons[2].button_pressed = 0;
			
			go_to_training_next = 1;
		}

		if (go_to_training_next){
			go_to_training_next = 0;
			perform_phase_training();	
			
			program_status.phase = BIT(PHASE_MAINPROG);
			set_green_led_mode(SHORT_HEARTBEAT_LED);
		}
	}
}

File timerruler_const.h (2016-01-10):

/*
 * timerruler_const.h
 *
 * Created: 13.12.2015 12:00:00
 * Author : AKAEM
 */ 

#ifndef _TIMER_RULER_CONS_H_
#define _TIMER_RULER_CONS_H_

#define NUM_LEDS						9
#define NUM_INTERVAL_LEDS				5
#define INTERVAL_LENGTH					15

// power saving mode wait this time in seconds go go to deep sleep
#define DEEP_SLEEP_SEC_MAINPROG			15
#define DEEP_SLEEP_SEC_CONFIG			15
#define DEEP_SLEEP_SEC_TRAINING_PAUSE	30


#define LED_OFF							0
// modes for green led (int and not bit mode)
#define SLOW_FLASHING_LED				1
#define FAST_FLASHING_LED				2
#define HEARTBEAT_LED					3
#define SHORT_HEARTBEAT_LED				4

// actual green led
#define LED9							8

// led effect 
#define LED_EFFECT_DELAY				80	// effect delay in ms between steps
#define LED_EFFECT_ORANGE				1
#define LED_EFFECT_ALL					2
#define LED_EFFECT_CENTER				3
#define ORANGE_LED_EFFECT_STEPS			5
#define ORANGE_LED_EFFECT_PERIOD 		3
#define ALL_LED_EFFECT_STEPS			11
#define ALL_LED_CENTER_EFFECT_STEPS		12
#define ALL_LED_CENTER_EFFECT_LR		0
#define ALL_LED_CENTER_EFFECT_RL		1

// define bit mask for all available and specific LEDs on PORTB and PORTD
#define LED_PORTB						0x02
#define LED_PORTD						0xFF
#define LED_PORTD_RED					0x1F
#define LED_PORTD_ORANGE				0xE0

// define bit mask for switches T1..3, all PORTC
#define SWITCH_T1						0
#define SWITCH_T2						1
#define SWITCH_T3						2
#define NUM_SWITCHES					3
#define SWITCH_MASK						0x07

// define different phases, bit mode
#define PHASE_MAINPROG					0	// something in main loop between different phases
#define PHASE_CONFIG					1
#define PHASE_TRAINING					2
#define PHASE_ACTIVE					3
#define PHASE_REST						4
#define PHASE_PAUSE						5
#define PHASE_SHOW_results				6
#define PHASE_RESET						7

#define CONFIG_INTERVAL_CNT				0	// counter for configuration of interval length
#define CONFIG_NR_INTERVAL_ACTIVE		1	// number of intervals in "active" phase
#define CONFIG_NR_INTERVAL_REST			2	// number of intervals in "rest" phase
#define CONFIG_NR_CYCLES				3	// number of cycles to perform ACT/REST phases
#define NUM_CONFIG_PARAMS				4

#define DEBOUNCE_THRESHOLD				50	// if x ms button high in a row -> button pressed

#endif

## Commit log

2015-12-24 change vars to button
2015-12-25 code cleanup, testing, cosmetic
    refactoring of button handling should be completed
2015-12-25 .led_steps_threshold size reduced, usage updated
2015-12-25 power optimization added for main prog and perform_config()
    power optimization using sleep() (using IDLE mode) and deep_sleep()
    using PWR_DOWN added for functions main program, configuration.
    perform_training() needs to be done next.
2015-12-25 power optimization for perform_training() added, code cleanup, new function go_to_appropriate_sleep_mode()
2015-12-26 corrected bug in T1 handling during perform_config()
    [main.c]
2015-12-28 moved routine from 1ms-Interrupt to 1s-Interrupt, defect with threshold handly solved
    [main.c]
2015-12-29 Recalculated timer0/1 values, added info to README.txt
    Recalculated timer values for 8 MHz quartz with CKDIV8 set, also added
    information about calculation and FUSE settings/COMPILER symbols to
    README.txt
2015-12-29 checked power consumption and added results to code/README.txt
2015-12-29 power consumption calculation, evaluated mA for each led an basic consumption
    [calc_power_consumption.xlsx]
2015-12-30 updated power consumption docs
    [calc_power_consumption.xlsx]
2016-01-06 updated EEPROM access according to issues #12, #13, #14
    - Use update, not write for EEPROM #12
    - Check that EEPROM is ready before next action #13
    - Deactivate interrupts before write #14
    [main.c]
2016-01-06 rewrite of orange led effect code
    solved issue #15 undefined orange led flickering
    [main.c]
2016-01-07 first rewrite done
    - added array for ALL LED EFFECT
    - using same counter for effects (orange/red leds)
    - resorted constants
    - still uncomfortable handling for fire effects (pre/post tasks) ->
    needs to be sorted out
    - test, test, test necessary!!!
2016-01-07 added fct led_effect_and_wait_to_complete(), some minor things
2016-01-07 resolved issue w/wrong phase bit set
    [main.c]
2016-01-07 added another effect w/all leds ("X" cross), some cleanup
2016-01-10 schematics/board, initial check-in
    [Timer-Ruler_CR2032_on_bottom.brd, Timer-Ruler_CR2032_on_bottom.sch, Timer-Ruler_CR2032_on_top.brd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]

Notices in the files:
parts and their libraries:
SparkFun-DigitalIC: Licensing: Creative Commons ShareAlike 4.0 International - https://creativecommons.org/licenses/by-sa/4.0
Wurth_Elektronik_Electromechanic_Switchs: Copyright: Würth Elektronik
